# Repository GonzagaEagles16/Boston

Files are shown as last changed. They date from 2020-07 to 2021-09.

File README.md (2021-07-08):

  

# [NotYetAcheron] 121-S-SM-MX-STM32-TH-WI (Codename "Boston")

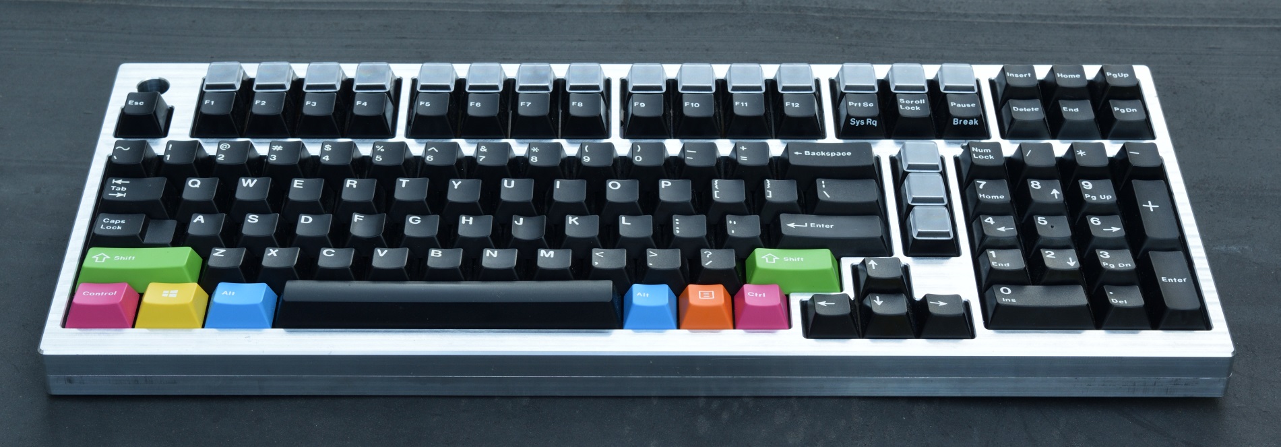
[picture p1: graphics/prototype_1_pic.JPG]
1st prototype

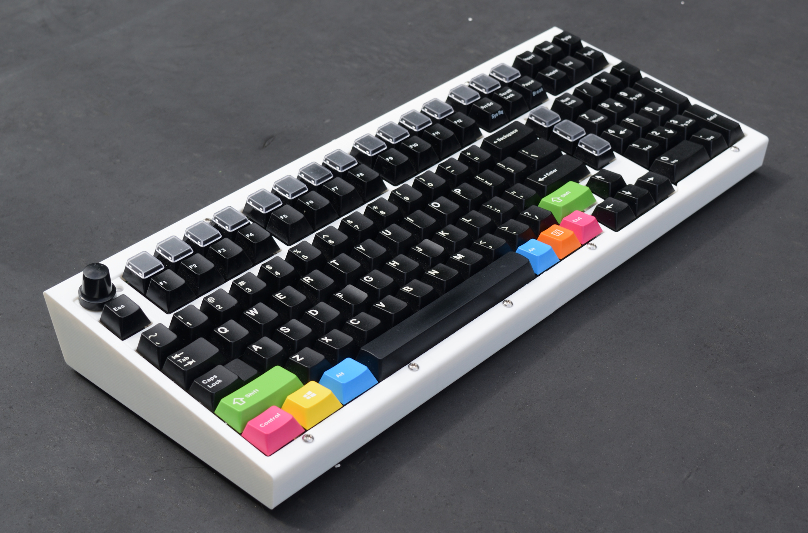
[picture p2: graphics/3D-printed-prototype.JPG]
3D-printed/FR4 version


## Introduction 
Boston is a compact 120% with a full-complement of 18 programmable keys, in a footprint 2u narrower than a full-size, and only about 1.5u wider than a 96%. Both a 3D-printed/FR4 case and a CNC aluminum case will be available.

The immediate inspiration for Boston was the DriftMechanics [Austin](https://github.com/Gondolindrim/Austin), as well as the [7-row Thinkpad keyboards](http://www.notebookreview.com/picture/?f=60846) found on Thinkpads of the T420 generation and older. The general idea was to make a narrower full-size that retained both the 2u numpad "0" and traditional 2x3 Ins/Del/Home/End/PgUp/PgDn nav block, by expanding vertically. 

The name is a pun off Austin, since the layout is derived from it. I also grew up in Boston. 

## Supported layouts

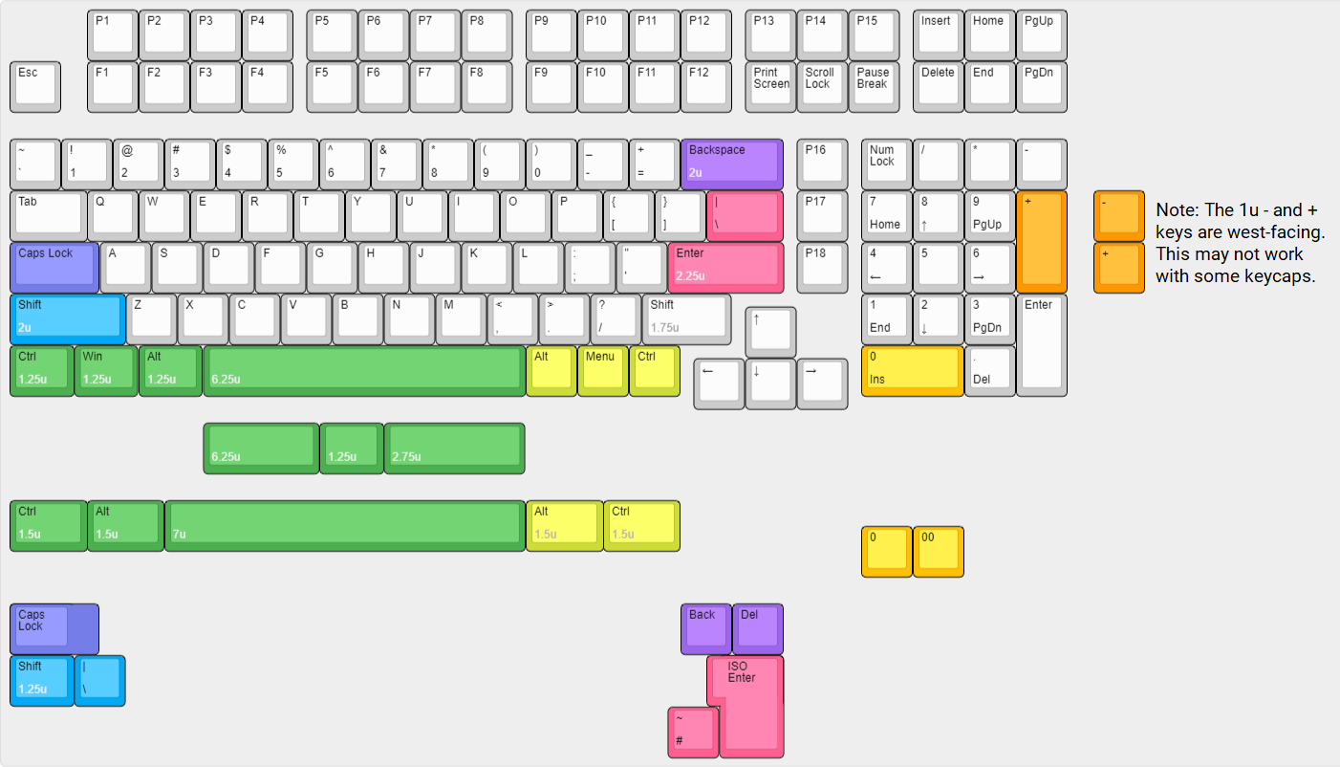
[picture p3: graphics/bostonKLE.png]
Boston layouts


Click [this link](http://www.keyboard-layout-editor.com/#/gists/75e63e00e1acc52cdb8eeda7f8ac4ba6) for the KLE file for Boston.

## Features:
* 121-key in standard ANSI configuration
* Alps EC11E rotary encoder above the Escape key 
* Full-size numpad with 2u "0" key
* Traditional 2x3 Ins/Del/Home/End/PgUp/PgDn navblock 
* Uses keys found in GMK base kits (except for programmable keys)
* RGBLED layer-status indicator light (layer-status indication not yet implemented)
* ISO enter key, split backspace, split numpad 0, split space, and WKL bottom row support 
* Optional through-hole LED backlight (dimmable as a single block only)
* USB-C
* STM32F072 controller running QMK. Circuitry is derived from the Austin. 
* QMK and Vial support 

## Status

This is a work in progress. The Geekhack Interest Check thread is [here](https://geekhack.org/index.php?topic=106501.0) on Geekhack. No GB date has been announced yet, though I've done a presale of PCBs, plates, and hardware for people willing to 3D print their own case. Updates will occasionally be posted there.

The current version (V0.5.2, in the "Boston - Current design" folder) has been prototyped and is working. Details about the PCB and plate files are available in the README files in thoes directories. I am currently working on a V0.6 for the PCB.

STL and STEP files for the 3D-printed/FR4 case are available under the "3D-printed case - parts" folder. Unfortunately, since I switched from Fusion to Atom3D in the middle of this project, I don't no longer have an up-to-date .f3d Fusion file that I can share, and I'm also essentially working off the STEP file. 

The aluminum version is still being prototyped. Unfortuantely, due to my likely arrangements with my vendor for this version, the case files for the aluminum version are unlikely to be open-sourced in the near future.

The QMK firmware files for this keyboard are [here](https://github.com/qmk/qmk_firmware/tree/master/keyboards/boston)

## PCB Renders 

Renders done with [tracespace.io](https://tracespace.io/).
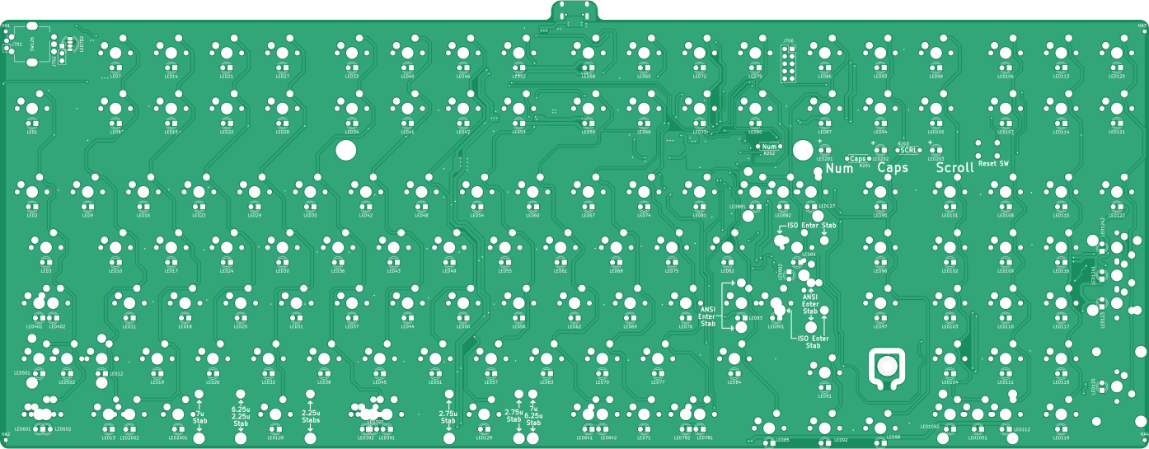
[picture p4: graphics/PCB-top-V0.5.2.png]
Keyboard top

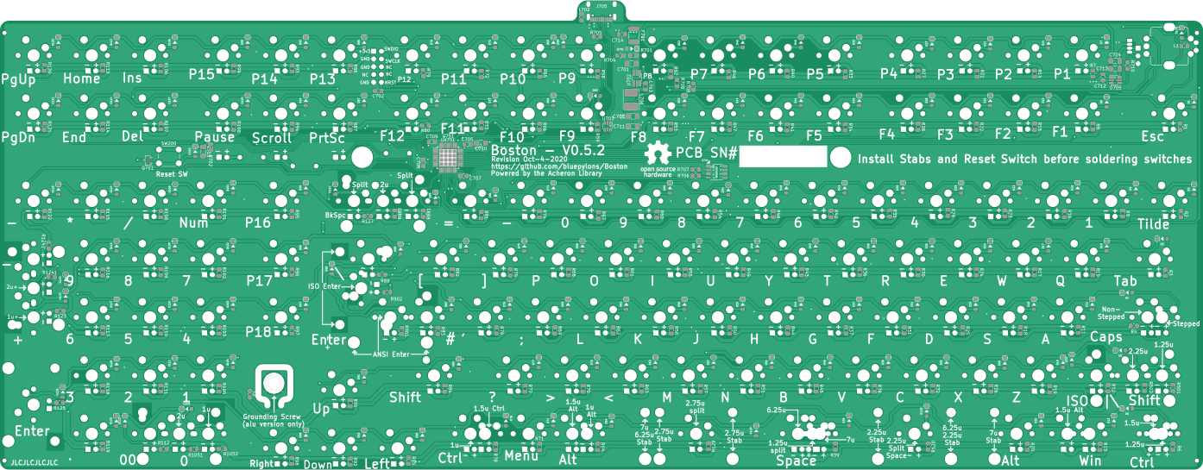
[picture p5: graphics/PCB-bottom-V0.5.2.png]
Keyboard bottom


## Copyright Notice

The PCB files and hardware designs are released under the [CERN OHL-W](https://ohwr.org/cern_ohl_w_v2.txt) license. The firmware is released under [GNU GPL V3](https://www.gnu.org/licenses/gpl-3.0.en.html) 

The map artwork in Single PCB design/3D printed case- FR4 part files/Bottom was created using OpenStreetMap data, © OpenStreetMap contributors, under OpenStreetMap's [conditions](https://www.openstreetmap.org/copyright). The resulting KiCAD footprint and PCB files for the bottom FR4 panel containing the artwork is specifically released under the [Open Data Commons Open Database License](https://opendatacommons.org/licenses/odbl/) 

The rubber feet, screws, nuts, and threaded inserts in the STEP file were remodelled from scratch, as most 3D models available online do not permit redistribution. 

## Libraries
This project uses the [Acheron Library](https://github.com/AcheronProject/AcheronLibrary).

The KiCAD files are done using the 5.99nightly builds, as the Acheron Library is currently on the nightlies and aren't compatible with the 5.1.6 stable build. This will be updated over to KiCAD V6 whenever that is released 

 The KiCAD files use project-specific paths to the Acheron Library. To set this up - in KiCAD, open Preferences > Configure Paths. Add a new entry, with ACHERONLIB for the name, and for the path, the directory where the AcheronLibrary folder resides in.

## Acknowledgements

Many thanks to:
* The [Acheron Project](http://acheronproject.com/) - the KiCAD library and the source files for the Austin have been invaluable for designing this board.
* The designers of the Austin (Driftingbunnies, PheonixStarr and Gondolindrim). The layout, schematics, and firmware were derived from that board.
* Gondolindrim, for assistance and feedback with the PCB design, as for running the Acheron project.
* KiCAD, for being an awesome free open-source PCB design tool.
* [Keyboard Layout Editor](http://www.keyboard-layout-editor.com/), where I designed the layout. 
* [Swill's plate generator](http://builder.swillkb.com/) and [Ai03's plate generator](https://kbplate.ai03.com/), which I used for making the plate.
* [Maperitive](http://maperitive.net/) and [OpenStreetMap](https://www.openstreetmap.org/#map=4/38.01/-95.84), which was used to generate the map artwork on the bottom of the 3D-printed/FR4 case.

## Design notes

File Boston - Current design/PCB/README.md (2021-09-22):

# PCBs

These are the PCB files. All PCBs so far have been manufactured at JLCPCB, so I include the JLCPCB SMT BOM and placement files.

All PCB files have been done on the KiCAD 5.99 nightly version, using the Acheron Library.

V0.6 is a work in progress. The planned changes for this revision are:
* Fix some minor silkscreen errors
* Implement the improved STM32 reset circuit designed by Gondolindrim, described [here](http://acheronproject.com/reset_article/principle.html) under "Improving over ishtob’s circuit". The reset circuit on past versions can get the microcontroller into the DFU bootloader for flashing, but can't do a hardware reset, which increases the risk of bricking in case a software reset is not possible (due to an interrupted flashing process, corrupted firmware, or other issue). On the new version, a short press does a simple reset, while a long press allows the microcontroller to enter the DFU bootloader. 
* Implement some EMI best practices, such as minimizing ground plane disruptions underneath the switching converter. I may run Boston through FCC testing at some point, so I would like to minimze EMI emissions. 

V0.6D is a planned version of V0.6 which is intended for use with a USB-C daughterboard, such as the [C3 Unified Daughterboard](https://github.com/ai03-2725/Unified-Daughterboard). This removes the USB-C connector and the ESD protection IC (as both of those will be on the daughterboard) and adds a 4-pin JST connector to connect to the daughterboard.

V0.6J is a planned version of V0.6 where all of the parts (except for the RGBLED and the reset switch, which are both through hole) can be assembled by JLCPCB. This may remove backlight LED support and uses a linear regulator for the 5V->3.3V conversion rather than a switching one (the AP63203WU-7 and inductor, which are not available at JLCPCB, are replaced with a TLV1117-33 LDO). Due to the reduced amount of available 3.3V current this means I may have to remove backlight support. Since this can be ordered fully-assembled from JLCPCB, this should make it easier for people to obtain PCBs.

V0.5.2 was what shipped in the Round 0 barebones kit sale, and has been verified to work. JLCPCB at the time was not able to solder on connectors, and was out of stock of STM32F072 microcontrollers, so those parts are not included on the manufacturing files. JLCPCB also did not carry the fuse, the AP63203WU-7 buck controller, or the buck controller inductor, so those parts are not included in the manufacturing files for JLCPCB SMT, and were soldered on by hand. 

Older PCB files are not included but can be accessed through the Git history.

## Older PCB Changelog

* V0.5.2 - October 6, 2020 - Removed a loop in the ground plane (which did not seem to affect functionality), and made some minor changes to the silkscreen. Increased thermal clearances around the RGBLED to make it easier to solder. Minor silkscreen fixes. Tested and working. People who bought Round 0 barebones kits received this PCB.

* V0.5.1 - September 23, 2020 - this fixed the routing errors in V0.5, and slightly improved the silkscreen graphics. The grounding screw hole is now connected to ground via a ferrite bead. Tested and working. Beta testers received fixed V0.5 and V0.5.1 boards.

* V0.5 - September 16, 2020 - added split space and WKL support, a grounding pad for the metal case, changed silkscreen somewhat, and changed the microcontroller footprint to be able to take both LQFP-48 and UFQFPN48 due to shortages of LQFP48 STM32F072's. This had several routing errors and requires some fixes for all features to work.

* V0.4 - August 11, 2020 - a complete redesign. Placed everything on a single PCB, with a centered USB-C port. The F-key clusters are moved closer to the main alpha keys. Switched to SMD diodes. Designed for both a 3D-printed/FR4 case, and a CNC metal case. Working. 

* V0.3 and earlier - these used a two-PCB design, with microcontroller, USB port, and associated components on the daughterboard, and a completely through-hole main PCB. Not compatible with the published case designs. The firmware is largely similar, though the matrix is different.

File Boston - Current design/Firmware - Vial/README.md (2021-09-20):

## Vial firmware

This is the firmware for [Vial](https://get.vial.today/), an open-source alternative to VIA that allows you to reprogram your keymap on-the-fly. You can flash the boston_vial.bin file using QMK Toolbox, dfu-util, or another utility. Vial should recognize the keyboard, and let you remap keys. 

The source files for Vial are available on the Vial-QMK repo [here](https://github.com/vial-kb/vial-qmk/tree/vial/keyboards/boston).

*Note that Vial is currently in beta, and there may be bugs. Use at your own risk. The Vial firmware for Boston has also only been tested on the standard layout, and although alt layouts (ISO, WKL, etc.) are supported they have not been tested and may have issues. Please contact me if there are any issues.* 

Current files use Vial Version 0.4.1

All files in this directory are licensed under the GNU General Public License V3.0.

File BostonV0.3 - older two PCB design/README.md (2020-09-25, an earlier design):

# Boston V0.3

1st prototype

These are the PCBs for an older version of Boston. The first two aluminum prototypes use this PCB, which places the controller on a separate daughterboard PCB. The PCB is not compatible with newer versions (the spacing between the F-row and the numrow is larger).

The matrix is different than newer versions and it supports fewer layout (no split backspace, WKL bottom row, or split spacebar support). As a result this has separate QMK files.

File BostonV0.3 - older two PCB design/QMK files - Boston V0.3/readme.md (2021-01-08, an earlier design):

# Boston

## Hardware
A compact 120% keyboard. 

3D-printed/FR4 version

Designed by Pylon. 

This keyboard is currently in IC - [Geekhack IC thread is here](https://geekhack.org/index.php?topic=106501.0). Group buy details will be posted once it is ready. PCB and 3D-printing files are available [here on its Github page](https://github.com/bluepylons/Boston).

## Instructions 
To compile:

    make boston:default

See the [build environment setup](https://docs.qmk.fm/#/getting_started_build_tools) and the [make instructions](https://docs.qmk.fm/#/getting_started_make_guide) for more information. Brand new to QMK? Start with our [Complete Newbs Guide](https://docs.qmk.fm/#/newbs).

To reset the board, use a pin to press the reset button on the underside of the keyboard. above the numlock key.

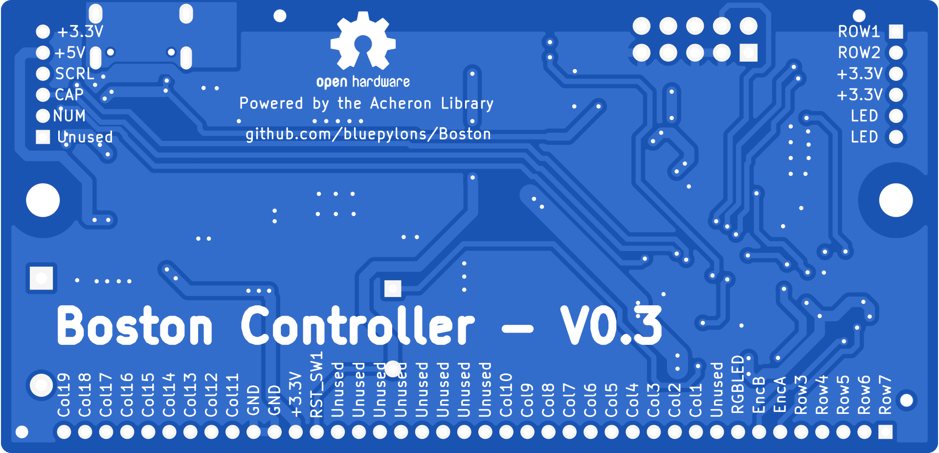
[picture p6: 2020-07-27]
graphics/controller-bottom-V0.3.png

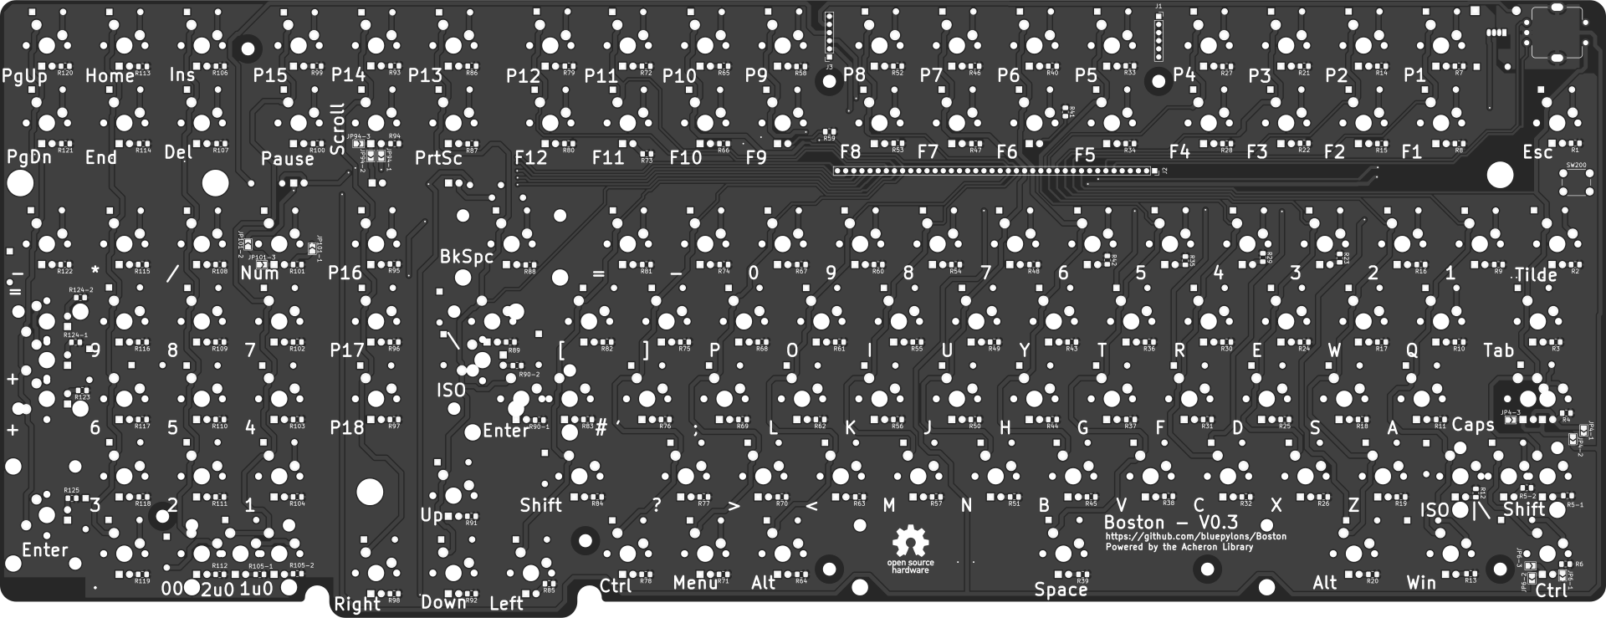
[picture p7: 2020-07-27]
graphics/keyboard-bottom-V0.3.png

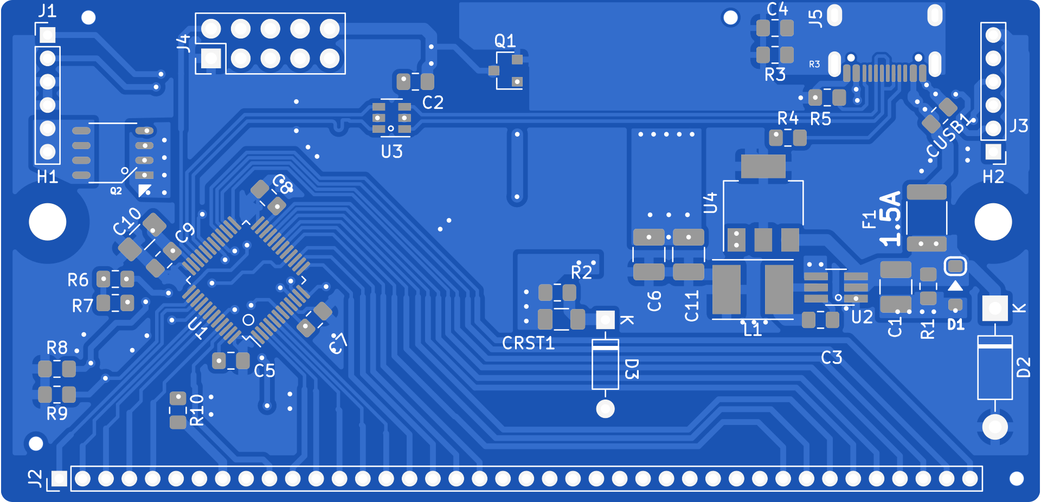
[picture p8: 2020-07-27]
graphics/controller-top-V0.3.png

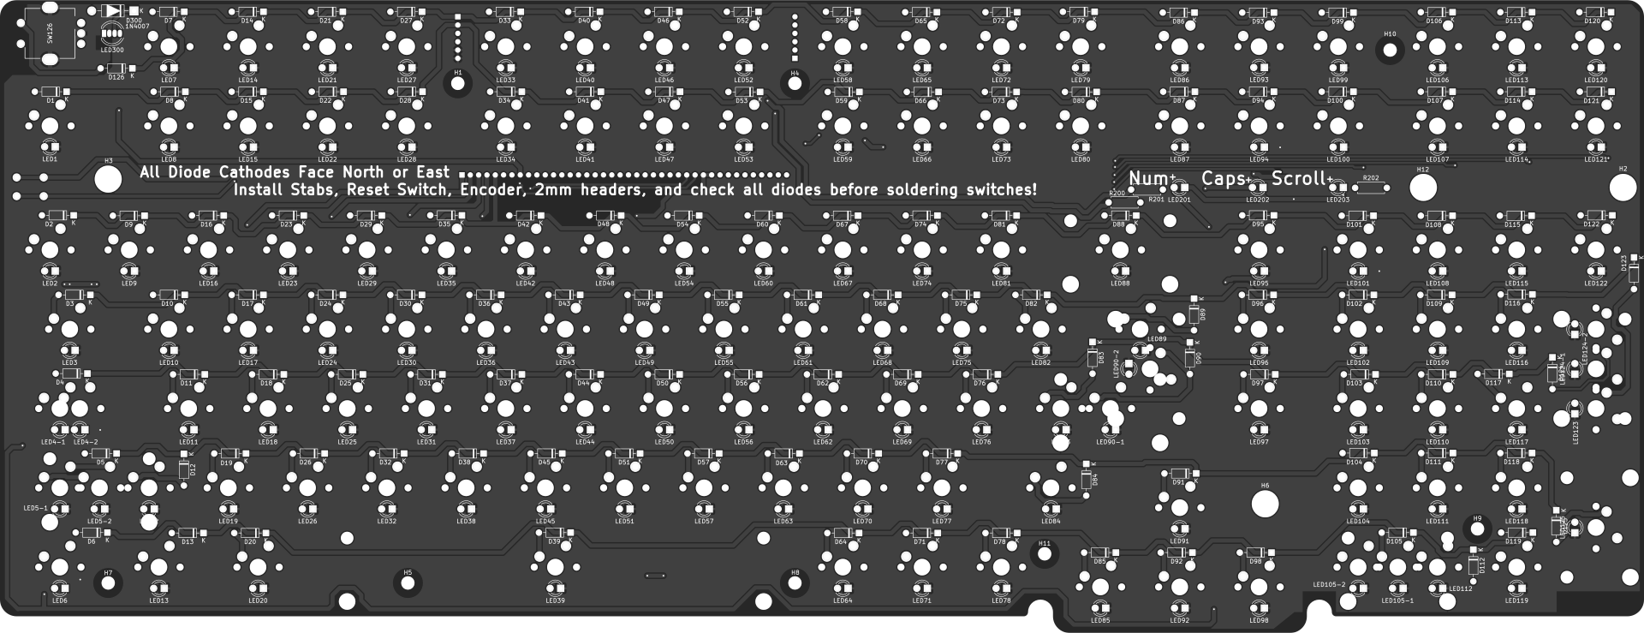
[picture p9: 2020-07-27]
graphics/keyboard-top-V0.3.png

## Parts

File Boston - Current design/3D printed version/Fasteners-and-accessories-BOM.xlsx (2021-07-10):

Description | Qty needed | McMaster-Carr P/N | Notes
M3x0.5, 6mm long ISO 7380 button head screw, stainless steel, Torx T10 head | 8 | 90991A112
M3x0.5, 10mm long ISO 7380 button head screw, stainless steell, Torx T10 head | 15 | 90991A114
M3x0.5 DIN 934 hex nut, zinc plated | 12 | 90591A250 | Recommend against using a stainless nut due to galling issues when using stainless-on-stainless
M2 5mm long Delta PT ® Torx head thread forming screw – 3BT-P8629-00-0025 | 14 | 96817A207 | Other M2 5mm-long self-tapping screws might work. There is also a stainless steel version of this screw – McMaster-Carr 96817A842
PEM tin-plated press-fit nut, M3x0.5. PEM P/N KF2-M3-ET | 11 | 95117A499
Rubber feet (3/8” diameter) – 3M Bumpon SJ5003 or equivalent | 4 | 95495K12

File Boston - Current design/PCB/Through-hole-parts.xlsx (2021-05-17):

Designator | Description | Qty needed | Manufacturer and Part Number | Notes
SW126 | Rotary Encoder | 1 | Alps EC11E18244A5 | Other Alps EC11E encoders can work, but may require changing the ENCODER_RESOLUTION parameter in QMK’s config.h
SW200 | Reset button | 1 | Tayda Electronics A-5127 | Any 6x6mm, 5mm tall, 4-leg normally open tact switch switch should work
LED702 | Through-hole 5mm RGBLED | 1 | APA106-F5 | The 5mm through-hole Neopixel LEDs that Adafruit and Sparkfun will work here. Note WS2812D-F5 will not work as it has a different pinout. Note that you will need the 3D-printed 5mm LED spacer if you want the LED to sit at the correct height.

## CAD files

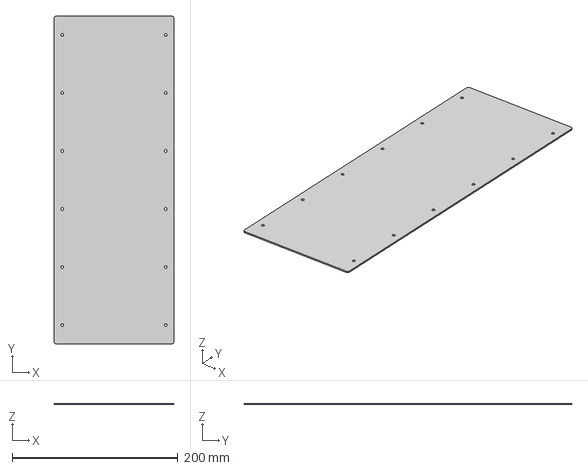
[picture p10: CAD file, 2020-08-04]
Boston - Current design/3D printed version/Bottom/Fusion-STEP-export.step
144.3 x 395.4 x 1.60 mm

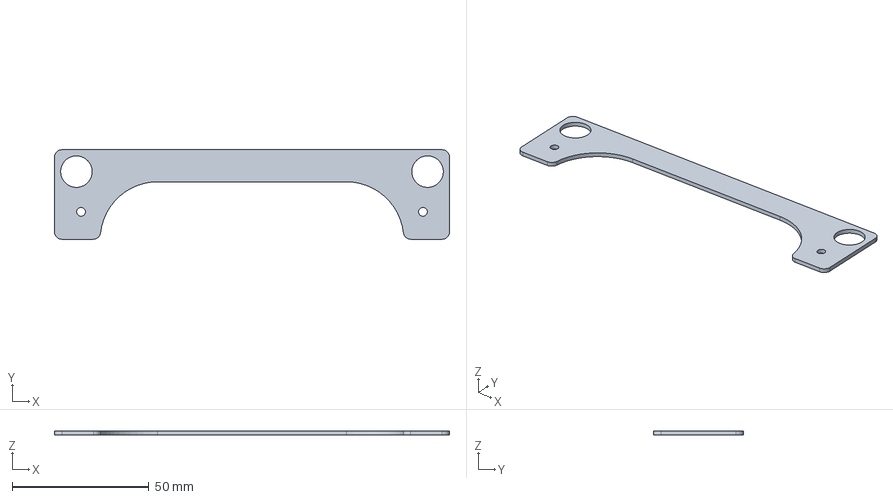
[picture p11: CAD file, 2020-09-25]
Boston - Current design/3D printed version/Bumpon holders/bumpon-holders.step
144.3 x 32.7 x 1.60 mm

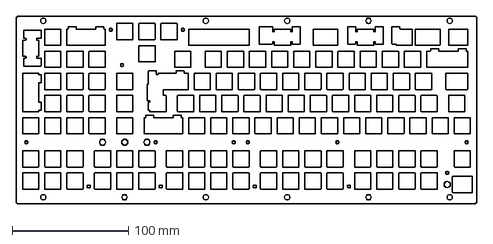
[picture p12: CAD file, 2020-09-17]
Boston - Current design/3D printed version/Plate/Fixed plate (split space)/plate-DXF-with-split-splace-support.dxf
396.0 x 161.0 mm

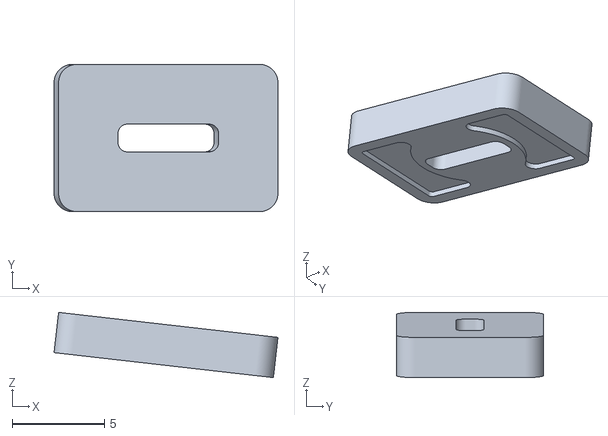
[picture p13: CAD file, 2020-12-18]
Boston - Current design/3D printed version/STLs/5mm-LED-spacer.stl
12.2 x 8.00 x 3.54

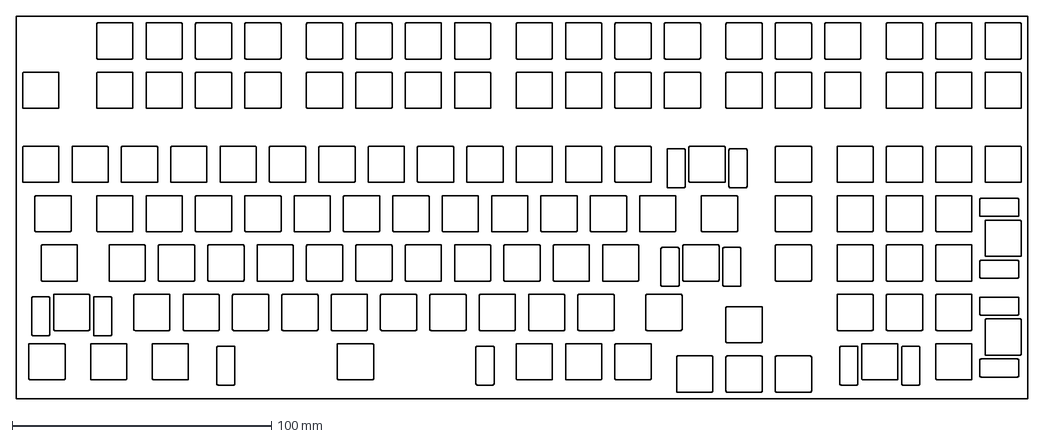
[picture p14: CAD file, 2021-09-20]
Boston - Current design/Metal version/Plate/FR4-fixed-layout-plate/plate-20210919-204106.dxf
390.5 x 147.6 mm

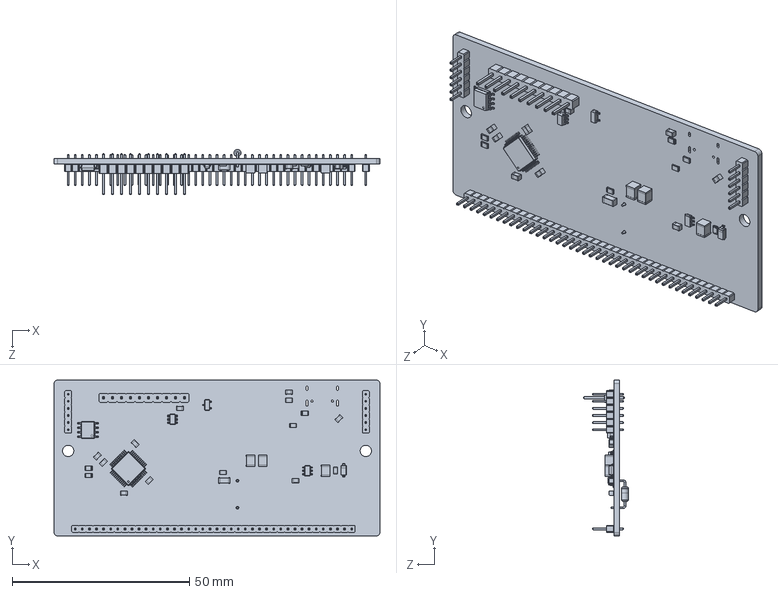
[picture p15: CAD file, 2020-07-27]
BostonV0.3 - two PCB design/KiCAD files - controller - STM32/Boston-controller-STM32.SLDPRT
92.0 x 44.0 x 12.8 mm

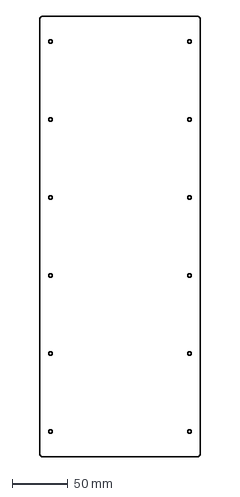
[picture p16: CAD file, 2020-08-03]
Boston - Current design/3D printed version/Bottom/bottom.dxf
144.3 x 395.4 mm

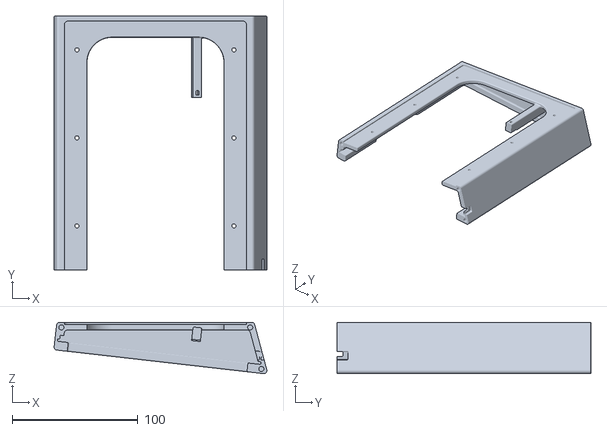
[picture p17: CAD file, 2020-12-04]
Boston - Current design/3D printed version/STLs/Right-half.stl
169.3 x 202.0 x 40.8

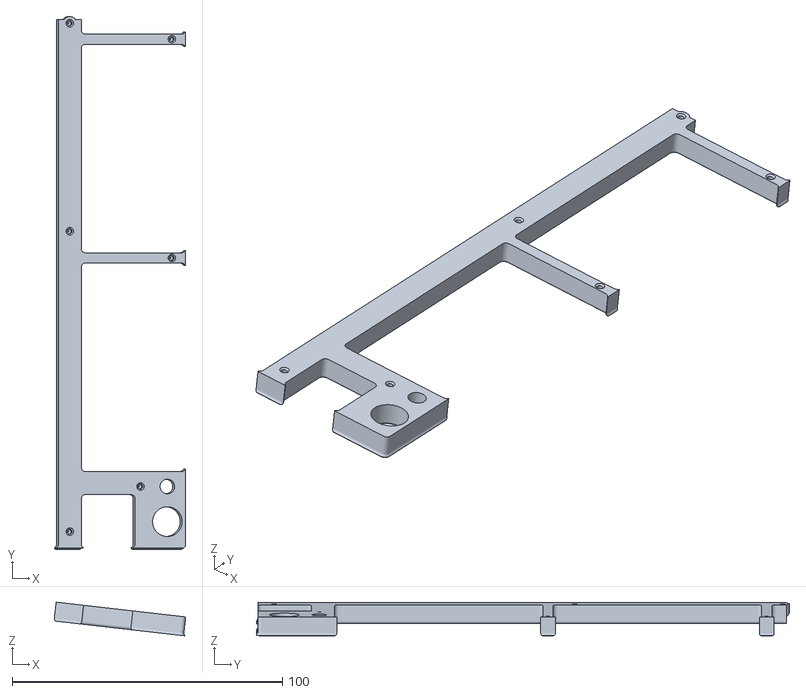
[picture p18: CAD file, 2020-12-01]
Boston - Current design/3D printed version/STLs/Left-key-separator.stl
48.7 x 197.3 x 12.5

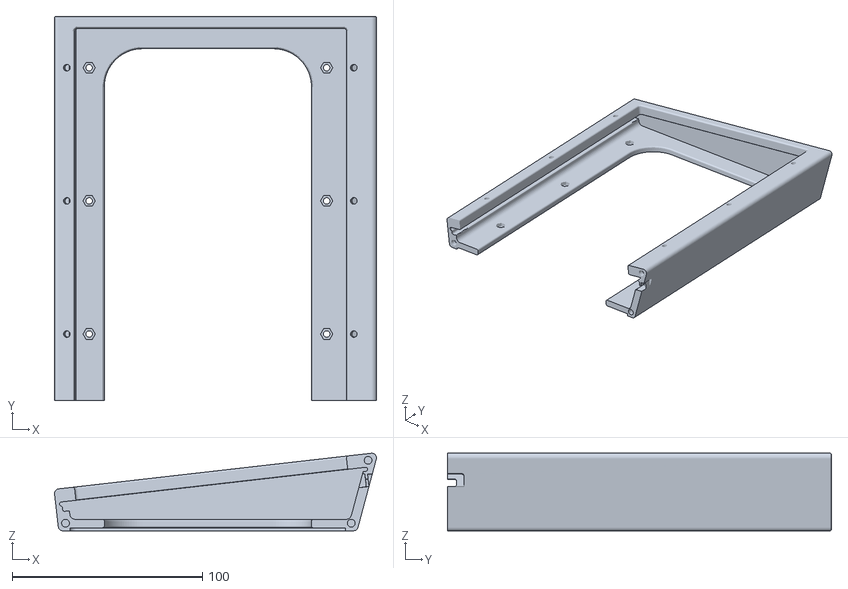
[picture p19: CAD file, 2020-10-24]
Boston - Current design/3D printed version/STLs/Left-half.stl
169.3 x 202.0 x 40.8

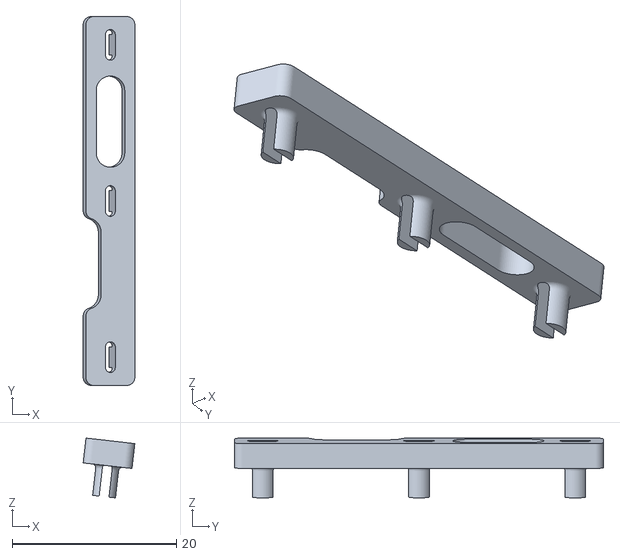
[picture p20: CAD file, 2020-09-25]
Boston - Current design/3D printed version/STLs/3mm-LED-spacer.stl
6.31 x 45.0 x 7.30

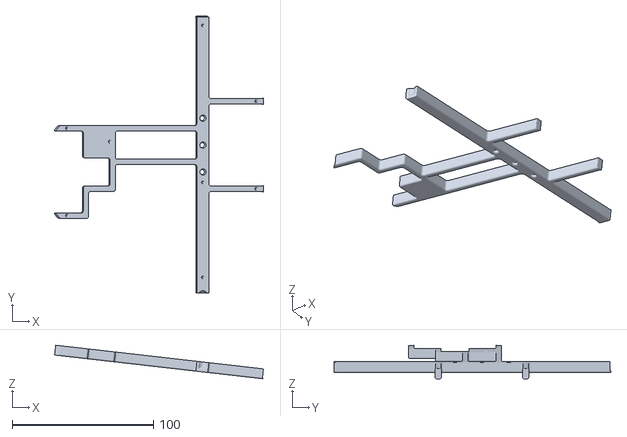
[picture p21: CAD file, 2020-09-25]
Boston - Current design/3D printed version/STLs/Right-key-separator.stl
148.0 x 195.9 x 23.8

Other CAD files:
Boston - Current design/3D printed version/Bottom/KiCAD files/bottom.step
Boston - Current design/3D printed version/Bumpon holders/bumpon-holders.dxf

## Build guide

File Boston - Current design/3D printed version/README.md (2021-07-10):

## Mechanical CAD

These are the CAD files for the 3D printed version. 

The master assembly is Boston-3D-printed-case.stp. The case was done with a mix of Fusion 360 and later Atom3D (after I decided to stop paying for Fusion) - due to the mix of CAD programs used the master file is actually not particularly editable, so I decided to just provide it as a STEP file that can be opened in any CAD program.

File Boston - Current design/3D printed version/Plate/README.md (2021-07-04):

# Plate files for the 3D-printed version

These are the FR4 plate files.These can be manufactured at any PCB fab. 

The "Current plate" has not been tested, but has been verified in CAD. The sole change is that this fixes the mistake with the numpad stabilizer cutout being flipped on the older plates. That is the only thing that has changed, and the files have been checked in CAD. 

The "Plate that shipped with V0.5.2 PCBs" has been tested, but as noted, the numpad Enter key stabilizer cutout is backwards. This results in the stab wires hitting the cutout, which results in a "clack" sound on the return. This can be fixed by filing the opening slightly. 

The "Old Plate' does not support split space or alternate bottom row layouts. This also has no solder mask on the top side as I wanted to see what the shiny HASL-Leadfree finish looked like (it ended up being inconsistent, so I opted for solder mask on the later versions). This also has the mistake on the numpad Enter key stabilizer cutout. This was used for the very first prototype, and is confirmed to work.

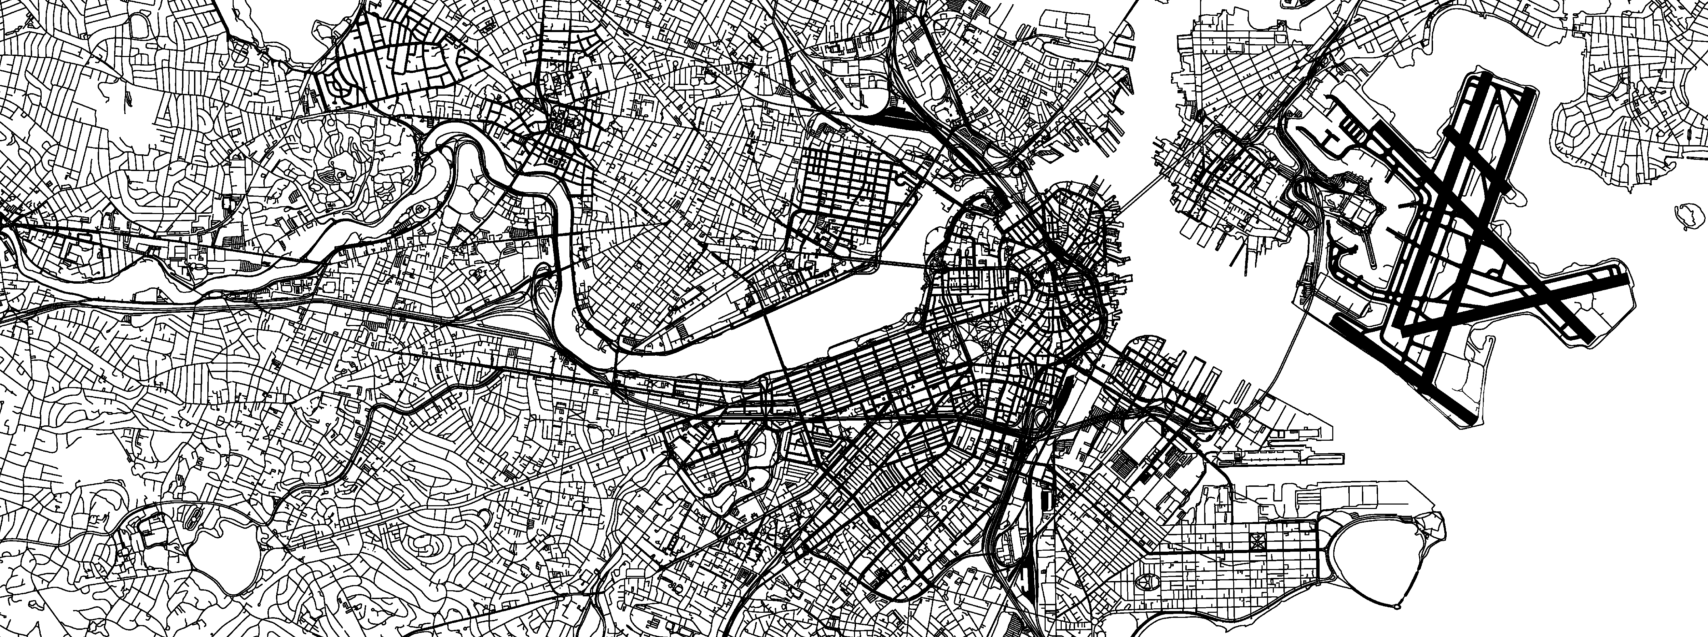
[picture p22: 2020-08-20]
Boston - Current design/3D printed version/Bottom/Artwork files (courtesy OpenStreetMap)/boston-streets-13-low-res.png

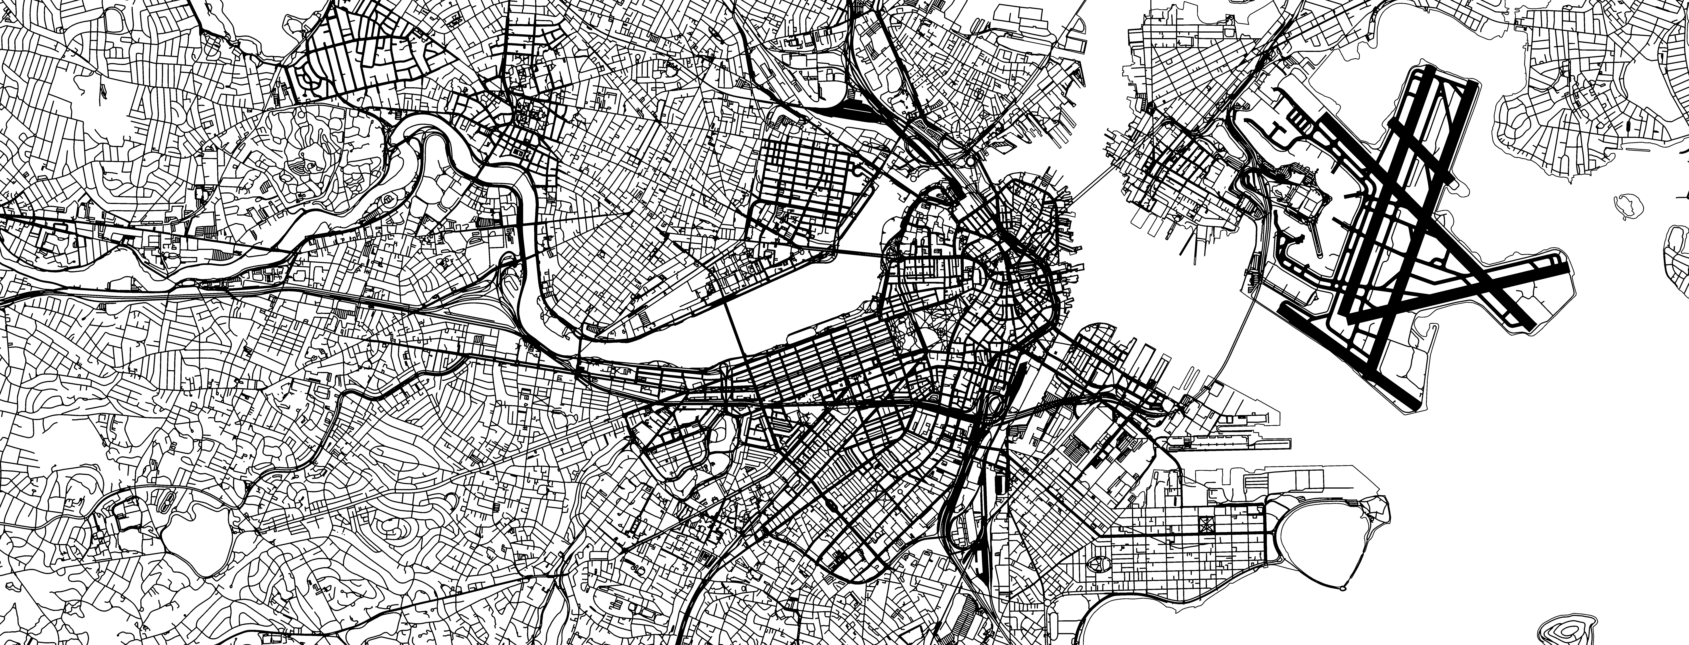
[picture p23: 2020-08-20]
Boston - Current design/3D printed version/Bottom/Artwork files (courtesy OpenStreetMap)/boston-streets-8.png

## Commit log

2020-07-27 Accidentally deleted directory, re-initializing
    [Boston-controller-STM32.SLDPRT, Boston-controller-STM32.kicad_pcb, Boston-controller-STM32.kicad_sch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]
2020-07-27 Finalized layout
    [Boston-keyboard-S.kicad_sch]
2020-07-28 Gave single PCB design its own folder
    [Boston-controller-STM32.SLDPRT, Boston-controller-STM32.kicad_pcb, Boston-controller-STM32.kicad_sch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]
2020-07-28 Reorganized single PCB design into own folder
    [Boston-controller-STM32.SLDPRT, Boston-controller-STM32.kicad_pcb, Boston-controller-STM32.kicad_sch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]
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2020-07-30 Silkscreen revisions
    [Boston-keyboard-S.kicad_sch]
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2020-08-03 Made FR4 plate for 3D printed case
    [FR4-plate.kicad_pcb, FR4-plate.kicad_sch, hole-locations.csv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]
2020-08-03 Added file and graphics for bottom plate
    [bottom.dxf, bottom.kicad_sch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]
2020-08-03 Added more FR4 part files
    [bottom.kicad_sch, bumpon-holders.dxf, hole-locations.csv]
2020-08-04 Updated graphics on bottom
    [Fusion-STEP-export.step, bottom-clean.kicad_pcb, bottom-clean.kicad_sch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]
2020-08-06 Updated plate and bottom for 3D-printed case
    [FR4-plate.kicad_pcb, FR4-plate.kicad_sch, bottom.kicad_sch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]
2020-08-06 Created Gerbers for bottom
    Normally I don't include Gerbers in the Github repo, but these Gerbers took 13 hours to create due to the artwork involved, so I will include them.
2020-08-06 Added drill files to Gerbers
    [bottom-NPTH.drl, bottom-PTH.drl]
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2020-08-07 Updated RGBLED - pin 2 common anode instead of pin 1
    Due to available RGB LEDs on JLCPCB
    [Boston-keyboard-S.kicad_sch]
2020-08-08 Cleaned up some deleted traces from some KiCAD bug
2020-08-08 Restored some V0.3 files that were accidentally deleted
    [Boston-controller-STM32.SLDPRT, Boston-controller-STM32.kicad_pcb, Boston-controller-STM32.kicad_sch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]
2020-08-09 Remade files due to file corruption bug in KiCAD
    https://gitlab.com/kicad/code/kicad/-/issues/5120
    [Boston-keyboard-S.kicad_sch]
2020-08-11 Added LED daughterboard
    [LED-daughterboard.dxf, LED-daughterboard.kicad_pcb, LED-daughterboard.kicad_sch]
2020-08-11 Updated RGB LED location
    Now moved to daughterboard, with the goal to underglow the encoder knob.
    [Boston-keyboard-S.kicad_sch]
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2020-08-14 Silkscreen changes
    [Boston-keyboard-S.kicad_sch, LED-daughterboard.kicad_pcb]
2020-08-20 Reorganized files
    [Boston-keyboard-S-B_Cu.gbr, Boston-keyboard-S-B_Mask.gbr, Boston-keyboard-S-B_SilkS.gbr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]
2020-08-21 Added thermals to PEM nut holes to make soldering easier
    [FR4-plate-new.kicad_pcb]
2020-08-21 Moved components away from USB-C conn to improve hand solderability
    In case I go with JLCPCB PCBA, who won't solder the USB-C connector. Moved the passives away from that connector to make it easier to hand-solder the USB-C connector.
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2020-08-21 Minor silkscreen fix (had =instead of - on the numpad silk)
2020-08-21 Flipped encoder footprint
    [Boston-keyboard-S.kicad_sch]
2020-08-21 Unflipped encoder, ended up editing the footprint
    [Boston-keyboard-S.kicad_sch]
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2020-09-11 Added WKL and 1.5u bottom row, added grounding hole, updated silkscreens
    [Boston-keyboard-S.kicad_sch]
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2020-09-16 Added UFQFPN48 alternate footprint for STM32; removed vias from underneath pads
    [Boston-keyboard-S.kicad_sch]
2020-09-17 Updated bottom
    [BOM-9-16.xls, Boston-keyboard-S.kicad_sch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]
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2020-09-18 Edited BOM and POS files to send to JLC
    [BOM-9-16.xls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]
2020-09-18 Final revisions before sending to JLCPCB on 9/18/2020
    [Boston-keyboard-S.kicad_sch]
2020-09-18 Fixed silkcreen on FR4 plate
    [FR4-plate-new.kicad_pcb]
2020-09-20 Added top-side solder mask to plate to prevent soldering nuts the wrong way
    [FR4-plate-new.kicad_pcb]
2020-09-21 Fixed error on D78 (overlaps with switch pad)
2020-09-23 Updated silkscreen (increased versioning after noticing diode mistake)
2020-09-23 Added ferrite to grounding wire
    [Boston-keyboard-S.kicad_sch]
2020-09-25 Restored various accidentally deleted files
    [bumpon-holders.kicad_pcb, bumpon-holders.kicad_sch, bumpon-holders.step]
2020-09-25 BOM for main PCB
    [BOM-9-22.xls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]
2020-09-25 LED daughterboard for the aluminum version
    [LED-daughterboard.step]
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2020-09-25 Renaming some folders
    [BOM-9-16.xls, BOM-9-22.xls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]
2020-10-03 Removed some Gerber files
    [LED-daughterboard-B_Cu.gbr, LED-daughterboard-B_Mask.gbr, LED-daughterboard-B_Paste.gbr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]
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2020-10-05 Clarified errors in V0.5 (+3.3V and GND were in fact not shorted)
2020-10-18 Reduced size of the 5mm RGBLED LED spacer (the current version is too tall)
    [5mm-LED-spacer.stl]
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2020-10-24 Improved clearance between the case and the front PEM nuts
    [Left.stl, Right.stl]
2020-10-25 Renamed case files to make more sense
    [Left-half.stl, Left-key-separator.stl, Right-half.stl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]
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2020-11-07 Tightened up clearances on M2 holes, added solder mask back onto the bottom layer
    [FR4-plate-new.kicad_pcb]
2020-11-07 Various silkscreen updates
    [Boston-keyboard-S.kicad_sch]
2020-12-01 Reduced gap between left and right key separators
    [Left-key-separator.stl]
2020-12-01 Changed some stuff around the reset button
    [Right-half.stl]
2020-12-04 Previous STL may have been corrupted
    [Right-half.stl]
2020-12-18 Updated dimensions
    [5mm-LED-spacer.stl]
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2021-01-10 Added RGB LED initialization color so it doesn't start on random color
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2021-03-06 Removed QMK Files as official QMK PR was approved
    Go here for QMK files now:
    https://github.com/qmk/qmk_firmware/tree/master/keyboards/boston
    [BOM-9-22.xls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]
2021-04-10 Cleaned up a bunch of files
    [BOM-revised.xls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]
2021-04-29 Revised PCB a bit to try to better control EMI
2021-05-17 Wrong reset circuit link
2021-05-17 Reorganized everything
    [3mm-LED-spacer.stl, 5mm-LED-spacer.stl, BOM-11-7.xls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]
2021-05-18 More EMI-related layout work
    [Boston-keyboard-S.kicad_sch]
2021-06-19 Clarified JLCPCB BOM and POS files do not include all parts; fixed incomplete sentences in README
    [BOM-11-7.xls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]
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2021-07-04 Ran DRC, checked everything over
    [Boston-keyboard-S.kicad_sch]
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2021-07-04 Renamed KiCAD files V0.6
    [Boston-keyboard-S.kicad_sch, Boston-keyboard-V06.kicad_sch]
2021-07-04 Started work on V0.6J
    [Boston-keyboard-V06J.kicad_sch]
2021-07-10 Clarified notes
    [Fasteners-and-accessories-BOM.xlsx]
2021-08-02 Added capacitors to reduce EMI from backlight
    [Boston-keyboard-V06.kicad_sch]
2021-08-03 More vias and tuning of ground planes for EMI purposes
    [Boston-keyboard-V06.kicad_sch]
2021-08-03 Initial work on V0.6D
    [Boston-keyboard-V06D.kicad_sch]
2021-09-16 Moved reset switch to underneath right shift
    [Boston-keyboard-V06D.kicad_sch]
2021-09-18 Switched to reverse-mount SMT LED for RGB
    [Boston-keyboard-V06D.kicad_sch]
2021-09-20 Work on metal version plate
    [FR4-fixed-layout-plate.kicad_pcb, FR4-fixed-layout-plate.kicad_sch, FR4-universal-layout-plate.kicad_pcb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]
2021-09-22 Finished work on fixed layout plate
    [FR4-fixed-layout-plate.kicad_sch]
